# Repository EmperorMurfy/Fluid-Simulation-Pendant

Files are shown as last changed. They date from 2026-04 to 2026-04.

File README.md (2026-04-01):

# Fluid Simulation Pendant
A Fluid Simulation Pendant Inspired by Mitxela

<table>
  <tr>
    <td></td>
    <td></td>
  </tr>
</table>

## Overview
Since January, I've been particularly inspired by Mitxela's Fluid Simulation Pendant.
A watch-sized device, it contains it's own charlieplexed LED display driven by an STM32.
This allows the device to run a particle simulation that responds to gravity in real time.
In other words, water is displayed on it's LED display that flows and settles naturally as you move.
 
As a beginner, I was thoroughly intrigued. This came at the perfect opportunity as I sought to enter electronic design.
So, with no former experience, I set out to build my own from scratch.

You can find my full devlog at [Blueprint](https://blueprint.hackclub.com/projects/14158)
--

## PCB
This project was designed in KiCAD. V1 utilized a lilypad design with two 2-layer daughter boards (see devlog).
V2 features a singular 4-layer board, merging V1's two daughter boards. It tackles significant issues from V1.

### Schematic


### PCB
<table>
  <tr>
    <td></td>
    <td></td>
  </tr>
</table>

## 3D View

<table>
  <tr>
    <td></td>
    <td></td>
  </tr>
</table>

## Setup

OBTAIN PCB
1) Download project files from Github. Use KiCAD to open hardware files.
2) Export & Upload to JLCPCB through Fabrication Toolkit
3) Select PCBA. Make sure you click on Standard + assemble on both sides. 
4) Follow on screen instructions. Verify BOM contents.

5) Purchase and await arrival.

While waiting, you can 3D print the case included in the CAD folder.
Download both "Case.3mf" and "Back Lid.3mf"
Alternatively, you can access the CAD on [Onshape](https://cad.onshape.com/documents/ce3587694f856aec528b28ab/w/4bfd7fa16d33233767ff6bdf/e/73e8d055661068f7b677968e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)

ASSEMBLY 
1) Solder PH1 pins on the back of the PCB at drilled holes labeled BOOT0, NRST, DEBUG_TMS, GND, DEBUG_TCK, 3.3V
2) Connect to Nucleo's ST-LINK, Connect to PCB
3) Install STM32CubeProgrammer and STM32CubeIDE
4) Open software folder from downloaded project files, select STM32.ioc (this should open STM32CubeProgrammer)
5) Select generate code (this should open STM32CubeIDE)
6) Replace the generated main.cp or cpp with main.cp from project files, click run to save
8) Install PCB to case - Be CAREFUL! Putting it at an angle with the USB-C pointed towards the opening helps.
9) Plug the battery into PCB's JST-2 port
10) Install the back lid + push in the watch glass

## BOM
In order to program this device, you will need F to F Jumper Wire and a Nucleo (I used Nucleo-F446RE). 
I didn't include these items as you may already have them. Disclaimer: The cost and quantity of PCB components were determined by JLCPCB.
JLCPCB sources their components from LCSC, but price may be inaccurate. Likewise, JLCPCB charged more components than required (e.g I only need 1040 Green 0402 LEDs, not 1045)
Likewise, you'll need to order 5 PCBs & 2 PCBA minimum. I ordered 5 PCBs + associated PCBA. 

|Item |Qty |Cost  |URL |Reference |Mfg Part # |
|---|----|---|---|---|---|
|PCB |5 |$14.90|https://jlcpcb.com/ |- |- |
|4.7uF-0402 |20  |$0.11 |https://www.lcsc.com/product-detail/C23733.html |C1,C8 |CL05A475MP5NRNC |
|100nF-0402 |40  |$0.05 |https://www.lcsc.com/product-detail/C1525.html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 |C2,C3,C4,C5,C6,C7 |CL05B104KO5NNNC |
|1uF |30  |$0.12 |https://www.lcsc.com/product-detail/C52923.html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 |C9,C10 |CL05A105KA5NQNC |
|1uF-0402 |- |- |https://www.lcsc.com/product-detail/C52923.html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 |C11,C12 |CL05A105KA5NQNC |
|Green 0402 LED |1045|$29.88|https://www.lcsc.com/product-detail/C74338.html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 |D6,D7,D8,D9,D10,D11,D20,D21,D22,D23,D24,D25,D26,D27,D28,D29,D35,D36,D37,D38,D39,D40,D41,D42,D43,D44,D45,D46,D50,D51,D52,D53,D54,D55,D56,D57,D58,D59,D60,D61,D62,D63,D66,D67,D68,D69,D70,D71,D72,D73,D74,D75,D76,D77,D78,D79,D81,D82,D83,D84,D85,D86,D87,D88,D89,D90,D91,D92,D93,D94,D95,D96,D97,D98,D99,D100,D101,D102,D103,D104,D105,D106,D107,D108,D109,D110,D111,D112,D113,D114,D115,D116,D117,D118,D119,D120,D121,D122,D123,D124,D125,D126,D127,D128,D129,D130,D131,D132,D133,D134,D135,D136,D137,D138,D139,D140,D141,D142,D143,D144,D145,D146,D147,D148,D149,D150,D151,D152,D153,D154,D155,D156,D157,D158,D159,D160,D161,D162,D163,D164,D165,D166,D167,D168,D169,D170,D171,D172,D173,D174,D175,D176,D178,D179,D180,D181,D182,D183,D184,D185,D186,D187,D188,D189,D190,D191,D194,D195,D196,D197,D198,D199,D200,D201,D202,D203,D204,D205,D206,D207,D211,D212,D213,D214,D215,D216,D217,D218,D219,D220,D221,D222,D228,D229,D230,D231,D232,D233,D234,D235,D236,D237,D246,D247,D248,D249,D250,D251|16-213/GHC-YR1S1/3T |
|Red 0402 LED |5 |$0.35 |https://www.lcsc.com/product-detail/C264407.html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|D257 |16-213/R6C-AQ2R2B/3T  |
|Conn_01x01_Pin |125 |- |- |J2,J3,J4,J5,J6,J7,J8,J9,J10,J11,J12,J13,J14,J15,J16,J17,J18,J19,J20,J21,J22,J23,J24,J25,J26 |DNP |
|Conn_01x02_Socket |5 |$2.19 |https://www.lcsc.com/product-detail/C160352.html?s_z=n_C160352 |J44 |B2B-PH-SM4-TB(LF)(SN) |
|22 |95  |$0.08 |https://www.lcsc.com/product-detail/C25092.html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 |R1,R2,R3,R4,R5,R6,R7,R8,R9,R10,R11,R12,R13,R14,R15,R16,R17 |0402WGF220JTCE |
|20K |20  |$0.02 |https://www.lcsc.com/product-detail/C25765.html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 |R18 |0402WGF2002TCE |
|1k |20  |$0.01 |https://www.lcsc.com/product-detail/C11702.html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 |R19 |0402WGF1001TC |
|10k |25  |$0.03 |https://www.lcsc.com/product-detail/C25744.html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 |R20, R21,R22 |0402WGF1002TCE |
|5.1K |20  |$0.02 |https://www.lcsc.com/product-detail/C25905.html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 |R23,R24 |0402WGF5101TCE |
|TestPoint |15  | |- |TP1,TP2,TP3 |DNP |
|STM32U575RGTx |5 |$27.84| |U1 |STM32U575RGT6 |
|ADXL363 |5 |$90.77|https://www.lcsc.com/product-detail/C579464.html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 |U2 |ADXL363BCCZ-RL7 |
|USBLC6-2P6 |5 |$1.23 |https://www.lcsc.com/product-detail/C15999.html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 |U3 |USBLC6-2P6 |
|MCP73832-2-MC |5 |$5.19 |https://www.lcsc.com/product-detail/C511264.html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 |U4 |MCP73832T-2ACI/MC |
|TPS7A20xxxDQN |5 |$1.59 |https://www.lcsc.com/product-detail/C46459900.html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 |U5 |TPS7A2033DQNR |
|TYPE-C_16P_QTWT |5 |$0.45 |https://www.lcsc.com/product-detail/C5187472.html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|USB1 |TYPE-C 16P QTWT |
|Setup Fee |- |$50.74|- |- |- |
|Stencil |- |$16.30|- |- |- |
|Feeders Loading Fee |- |$25.84|- |- |- |
|SMT Assembly |- |$5.23 |- |- |- |
|Packaging Fee | |$0.49 |- |- |- |
|JLCPCB Shipping |- |$50.04|- |- |- |
|JLCPCB Custom Duties & Taxes |- |$86.68|- |- |- |
|Li-Polymer 402025 150mAh 3.7V|5 |$29.75|https://www.digikey.com/en/products/detail/adafruit-industries-llc/1317/5054547 |- |- |
|PH1-01-UA |40  |$1.16 |https://www.digikey.com/en/products/detail/adam-tech/PH1-01-UA/9830231 |- |- |
|Digikey Shipping |- |$6.99 |- |- |- |
|Watch Glass 43mm Dia |1 |$7.69 |https://www.amazon.com/dp/B09QXCGNG6?ref_=ppx_hzsearch_conn_dt_b_fed_asin_title_1 | | |
|Total |- |$456  | | | |

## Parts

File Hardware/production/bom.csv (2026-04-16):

Designator | Footprint | Quantity | Value | LCSC Part #
C1, C8 | 0402 | 2 | 4.7uF-0402
C10, C9 | 0402 | 2 | 1uF
C11, C12 | 0402 | 2 | 1uF-0402
C2, C3, C4, C5, C6, C7 | 0402 | 6 | 100nF-0402
D10, D100, D101, D102, D103, D104, D105, D106, D107, D108, D109, D11, D110, D111, D112, D113, D114, D115, D116, D117, D118, D119, D120, D121, D122, D123, D124, D125, D126, D127, D128, D129, D130, D131, D132, D133, D134, D135, D136, D137, D138, D139, D140, D141, D142, D143, D144, D145, D146, D147, D148, D149, D150, D151, D152, D153, D154, D155, D156, D157, D158, D159, D160, D161, D162, D163, D164, D165, D166, D167, D168, D169, D170, D171, D172, D173, D174, D175, D176, D178, D179, D180, D181, D182, D183, D184, D185, D186, D187, D188, D189, D190, D191, D194, D195, D196, D197, D198, D199, D20, D200, D201, D202, D203, D204, D205, D206, D207, D21, D211, D212, D213, D214, D215, D216, D217, D218, D219, D22, D220, D221, D222, D228, D229, D23, D230, D231, D232, D233, D234, D235, D236, D237, D24, D246, D247, D248, D249, D25, D250, D251, D26, D27, D28, D29, D35, D36, D37, D38, D39, D40, D41, D42, D43, D44, D45, D46, D50, D51, D52, D53, D54, D55, D56, D57, D58, D59, D6, D60, D61, D62, D63, D66, D67, D68, D69, D7, D70, D71, D72, D73, D74, D75, D76, D77, D78, D79, D8, D81, D82, D83, D84, D85, D86, D87, D88, D89, D9, D90, D91 | 0402 | 200 | Green 0402 LED
D257 | 0402 | 1 | Red 0402 LED
D92, D93, D94, D95, D96, D97, D98, D99 | 0402 | 8 | Green 0402 LED
J10, J11, J12, J13, J14, J15, J16, J17, J18, J19, J2, J20, J21, J22, J23, J24, J25, J26, J3, J4, J5, J6, J7, J8, J9 | TestPoint_THTPad_D2.0mm_Drill1.0mm | 25 | Conn_01x01_Pin
J44 | JST_PH_B2B-PH-SM4-TB_1x02-1MP_P2.00mm_Vertical | 1 | Conn_01x02_Socket
R1, R10, R11, R12, R13, R14, R15, R16, R17, R2, R3, R4, R5, R6, R7, R8, R9 | 0402 | 17 | 22
R18 | 0402 | 1 | 20K
R19 | 0402 | 1 | 1k
R20, R21, R22 | 0402 | 3 | 10k
R23, R24 | 0402 | 2 | 5.1K
TP1, TP2, TP3 | TestPoint_Pad_2.0x2.0mm | 3 | TestPoint
U1 | LQFP-64_10x10mm_P0.5mm | 1 | STM32U575RGTx
U2 | Analog_LGA-16_3.25x3mm_P0.5mm_LayoutBorder3x5y | 1 | ADXL363
U3 | SOT-666 | 1 | USBLC6-2P6
U4 | DFN-8-1EP_3x2mm_P0.5mm_EP1.7x1.4mm | 1 | MCP73832-2-MC
U5 | Texas_X2SON-4_1x1mm_P0.65mm | 1 | TPS7A20xxxDQN
USB1 | TYPE-C_16P_QTWT | 1 | TYPE-C_16P_QTWT | C5187472

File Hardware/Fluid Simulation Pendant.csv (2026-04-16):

Reference | Mfg Part # | LCSC | Link | Qty | Value | DNP | Exclude from BOM | Exclude from Board | Footprint | Datasheet | Manufacturer
C1,C8 | CL05A475MP5NRNC |  |  | 2 | 4.7uF-0402 |  |  |  | Capacitor_SMD:C_0402_1005Metric | ~ | Murata Electronics
C2,C3,C4,C5,C6,C7 | CL05B104KO5NNNC |  |  | 6 | 100nF-0402 |  |  |  | Capacitor_SMD:C_0402_1005Metric | ~ | Murata Electronics
C9,C10 | CL05A105KA5NQNC |  |  | 2 | 1uF |  |  |  | Capacitor_SMD:C_0402_1005Metric | ~ | Murata Electronics
C11,C12 | CL05A105KA5NQNC |  |  | 2 | 1uF-0402 |  |  |  | Capacitor_SMD:C_0402_1005Metric | ~ | Murata Electronics
D6,D7,D8,D9,D10,D11,D20,D21,D22,D23,D24,D25,D26,D27,D28,D29,D35,D36,D37,D38,D39,D40,D41,D42,D43,D44,D45,D46,D50,D51,D52,D53,D54,D55,D56,D57,D58,D59,D60,D61,D62,D63,D66,D67,D68,D69,D70,D71,D72,D73,D74,D75,D76,D77,D78,D79,D81,D82,D83,D84,D85,D86,D87,D88,D89,D90,D91,D92,D93,D94,D95,D96,D97,D98,D99,D100,D101,D102,D103,D104,D105,D106,D107,D108,D109,D110,D111,D112,D113,D114,D115,D116,D117,D118,D119,D120,D121,D122,D123,D124,D125,D126,D127,D128,D129,D130,D131,D132,D133,D134,D135,D136,D137,D138,D139,D140,D141,D142,D143,D144,D145,D146,D147,D148,D149,D150,D151,D152,D153,D154,D155,D156,D157,D158,D159,D160,D161,D162,D163,D164,D165,D166,D167,D168,D169,D170,D171,D172,D173,D174,D175,D176,D178,D179,D180,D181,D182,D183,D184,D185,D186,D187,D188,D189,D190,D191,D194,D195,D196,D197,D198,D199,D200,D201,D202,D203,D204,D205,D206,D207,D211,D212,D213,D214,D215,D216,D217,D218,D219,D220,D221,D222,D228,D229,D230,D231,D232,D233,D234,D235,D236,D237,D246,D247,D248,D249,D250,D251 | 16-213/GHC-YR1S1/3T |  |  | 208 | Green 0402 LED |  |  |  | LED_SMD:LED_0402_1005Metric | ~ | Everlight Electronics Co Ltd
D257 | 16-213/R6C-AQ2R2B/3T |  |  | 1 | Red 0402 LED |  |  |  | LED_SMD:LED_0402_1005Metric | ~ | Everlight Electronics Co Ltd
J2,J3,J4,J5,J6,J7,J8,J9,J10,J11,J12,J13,J14,J15,J16,J17,J18,J19,J20,J21,J22,J23,J24,J25,J26 |  |  |  | 25 | Conn_01x01_Pin | DNP |  |  | TestPoint:TestPoint_THTPad_D2.0mm_Drill1.0mm | ~
J44 | B2B-PH-SM4-TB(LF)(SN) |  |  | 1 | Conn_01x02_Socket |  |  |  | Connector_JST:JST_PH_B2B-PH-SM4-TB_1x02-1MP_P2.00mm_Vertical | ~
R1,R2,R3,R4,R5,R6,R7,R8,R9,R10,R11,R12,R13,R14,R15,R16,R17 | 0402WGF220JTCE |  |  | 17 | 22 |  |  |  | Resistor_SMD:R_0402_1005Metric | ~ | YAGEO
R18 | 0402WGF2002TCE |  |  | 1 | 20K |  |  |  | Resistor_SMD:R_0402_1005Metric | ~
R19 | 0402WGF1001TC |  |  | 1 | 1k |  |  |  | Resistor_SMD:R_0402_1005Metric | ~ | YAGEO
R20 | 0402WGF1002TCE |  |  | 1 | 10k |  |  |  | Resistor_SMD:R_0402_1005Metric | ~ | YAGEO
R21,R22 | 0402WGF1002TCE |  |  | 2 | 10K |  |  |  | Resistor_SMD:R_0402_1005Metric | ~
R23,R24 | 0402WGF5101TCE |  |  | 2 | 5.1K |  |  |  | Resistor_SMD:R_0402_1005Metric | ~
TP1,TP2,TP3 |  |  |  | 3 | TestPoint | DNP |  |  | TestPoint:TestPoint_Pad_2.0x2.0mm | ~
U1 | STM32U575RGT6 |  |  | 1 | STM32U575RGTx |  |  |  | Package_QFP:LQFP-64_10x10mm_P0.5mm | https://www.st.com/resource/en/datasheet/stm32u575rg.pdf | STMicroelectronics
U2 | ADXL363BCCZ-RL7 |  |  | 1 | ADXL363 |  |  |  | Sensor_Motion:Analog_LGA-16_3.25x3mm_P0.5mm_LayoutBorder3x5y | https://www.analog.com/media/en/technical-documentation/data-sheets/ADXL363.pdf | Analog Devices Inc.
U3 | USBLC6-2P6 |  |  | 1 | USBLC6-2P6 |  |  |  | Package_TO_SOT_SMD:SOT-666 | https://www.st.com/resource/en/datasheet/usblc6-2.pdf | STMicroelectronics
U4 | MCP73832T-2ACI/MC |  |  | 1 | MCP73832-2-MC |  |  |  | Package_DFN_QFN:DFN-8-1EP_3x2mm_P0.5mm_EP1.7x1.4mm | http://ww1.microchip.com/downloads/en/DeviceDoc/20001984g.pdf | Microchip Tech
U5 | TPS7A2033DQNR |  |  | 1 | TPS7A20xxxDQN |  |  |  | Package_SON:Texas_X2SON-4_1x1mm_P0.65mm | https://www.ti.com/lit/ds/symlink/tps7a20.pdf | Texas Instruments
USB1 | TYPE-C 16P QTWT | C5187472 |  | 1 | TYPE-C_16P_QTWT |  |  |  | JLCImport:TYPE-C_16P_QTWT | https://wmsc.lcsc.com/wmsc/upload/file/pdf/v2/lcsc/2209291730_SHOU-HAN-TYPE-C-16P-QTWT_C5187472.pdf | SHOU HAN

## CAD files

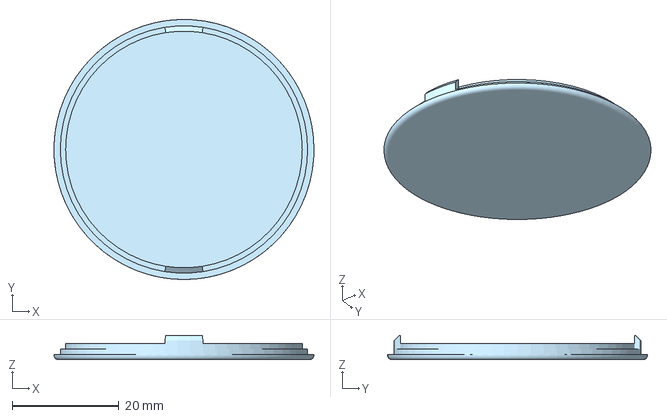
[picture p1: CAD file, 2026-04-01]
CAD/Back Lid.3mf
48.8 x 48.8 x 4.58 mm

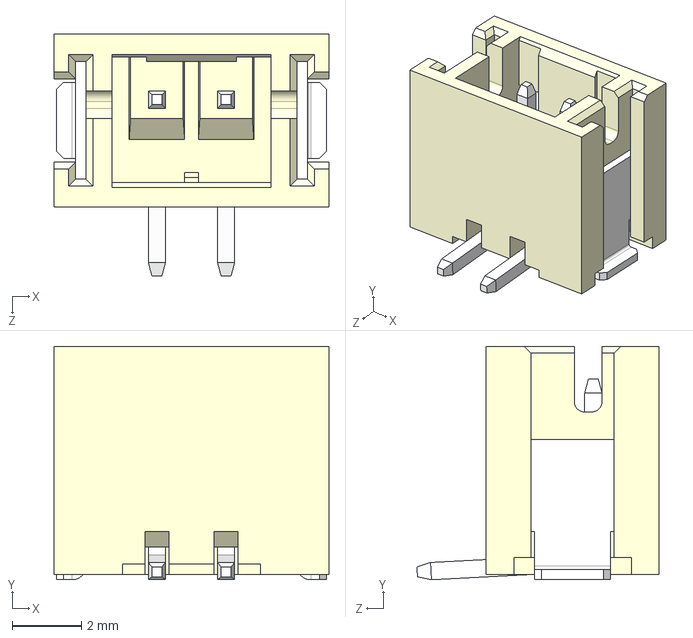
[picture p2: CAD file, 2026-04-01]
Hardware/B2B-PH-SM4-TB(LF)(SN).STEP
7.95 x 6.75 x 7.00 mm

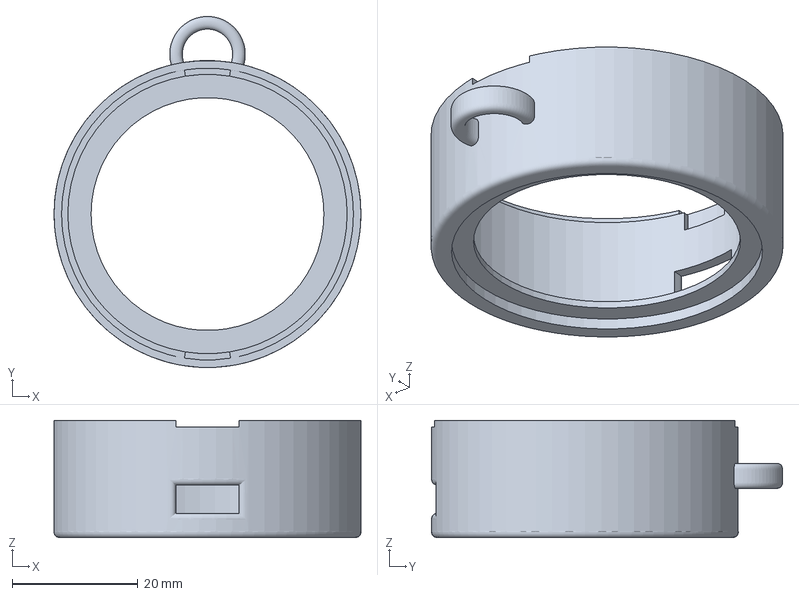
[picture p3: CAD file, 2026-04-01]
CAD/Case.3mf
48.8 x 55.8 x 18.6 mm

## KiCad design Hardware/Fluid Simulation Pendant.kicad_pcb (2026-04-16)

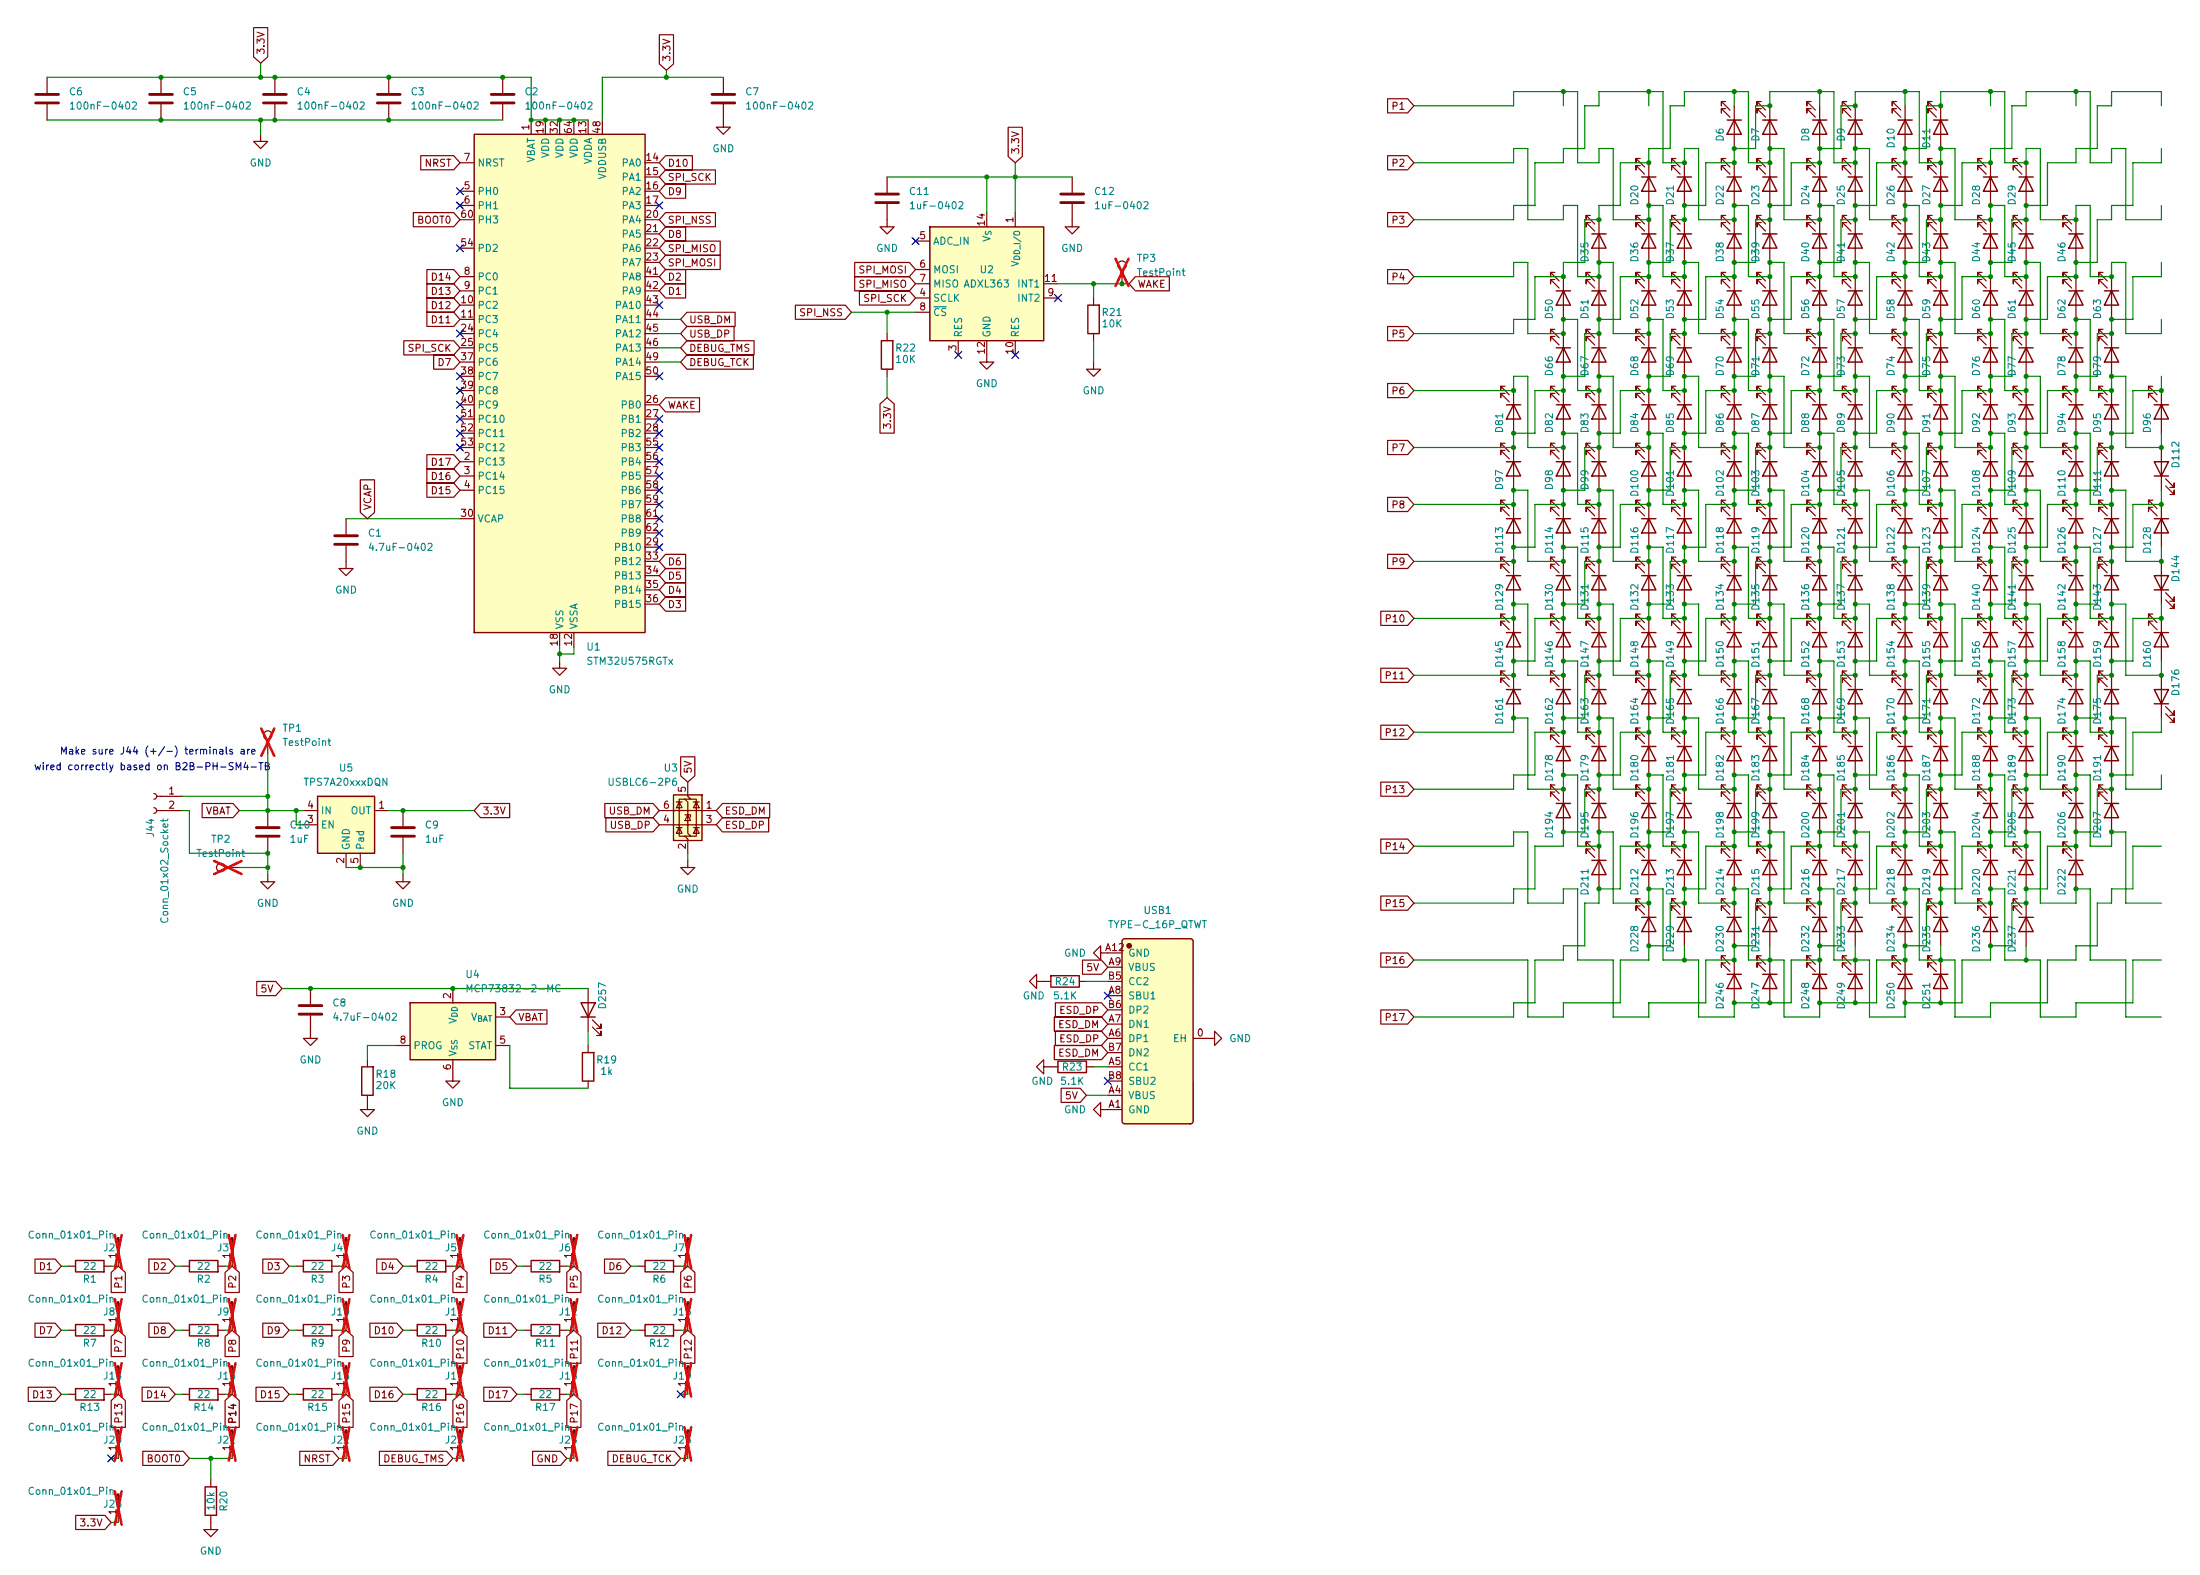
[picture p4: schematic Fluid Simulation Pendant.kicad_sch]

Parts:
C1, C8: 4.7uF-0402; C_0402_1005Metric; Mfg Part # CL05A475MP5NRNC
C2, C3, C4, C5, C6, C7: 100nF-0402; C_0402_1005Metric; Mfg Part # CL05B104KO5NNNC
C9, C10: 1uF; C_0402_1005Metric; Mfg Part # CL05A105KA5NQNC
C11, C12: 1uF-0402; C_0402_1005Metric; Mfg Part # CL05A105KA5NQNC
D6, D7, D8, D9, D10, D11, D20, D21, D22, D23, D24, D25, D26, D27, D28, D29, D35, D36, D37, D38, D39, D40, D41, D42, D43, D44, D45, D46, D50, D51, D52, D53, D54, D55, D56, D57, D58, D59, D60, D61, D62, D63, D66, D67, D68, D69, D70, D71, D72, D73, D74, D75, D76, D77, D78, D79, D81, D82, D83, D84, D85, D86, D87, D88, D89, D90, D91, D92, D93, D94, D95, D96, D97, D98, D99, D100, D101, D102, D103, D104, D105, D106, D107, D108, D109, D110, D111, D112, D113, D114, D115, D116, D117, D118, D119, D120, D121, D122, D123, D124, D125, D126, D127, D128, D129, D130, D131, D132, D133, D134, D135, D136, D137, D138, D139, D140, D141, D142, D143, D144, D145, D146, D147, D148, D149, D150, D151, D152, D153, D154, D155, D156, D157, D158, D159, D160, D161, D162, D163, D164, D165, D166, D167, D168, D169, D170, D171, D172, D173, D174, D175, D176, D178, D179, D180, D181, D182, D183, D184, D185, D186, D187, D188, D189, D190, D191, D194, D195, D196, D197, D198, D199, D200, D201, D202, D203, D204, D205, D206, D207, D211, D212, D213, D214, D215, D216, D217, D218, D219, D220, D221, D222, D228, D229, D230, D231, D232, D233, D234, D235, D236, D237, D246, D247, D248, D249, D250, D251: Green 0402 LED; LED_0402_1005Metric; Mfg Part # 16-213/GHC-YR1S1/3T
D257: Red 0402 LED; LED_0402_1005Metric; Mfg Part # 16-213/R6C-AQ2R2B/3T
J2, J3, J4, J5, J6, J7, J8, J9, J10, J11, J12, J13, J14, J15, J16, J17, J18, J19, J20, J21, J22, J23, J24, J25, J26: Conn_01x01_Pin; TestPoint_THTPad_D2.0mm_Drill1.0mm; not fitted
J44: Conn_01x02_Socket; JST_PH_B2B-PH-SM4-TB_1x02-1MP_P2.00mm_Vertical; Mfg Part # B2B-PH-SM4-TB(LF)(SN)
R1, R2, R3, R4, R5, R6, R7, R8, R9, R10, R11, R12, R13, R14, R15, R16, R17: 22; R_0402_1005Metric; Mfg Part # 0402WGF220JTCE
R18: 20K; R_0402_1005Metric; Mfg Part # 0402WGF2002TCE
R19: 1k; R_0402_1005Metric; Mfg Part # 0402WGF1001TC
R20: 10k; R_0402_1005Metric; Mfg Part # 0402WGF1002TCE
R21, R22: 10K; R_0402_1005Metric; Mfg Part # 0402WGF1002TCE
R23, R24: 5.1K; R_0402_1005Metric; Mfg Part # 0402WGF5101TCE
TP1, TP2, TP3: TestPoint; TestPoint_Pad_2.0x2.0mm; not fitted
U1: STM32U575RGTx; LQFP-64_10x10mm_P0.5mm; Mfg Part # STM32U575RGT6
U2: ADXL363; Analog_LGA-16_3.25x3mm_P0.5mm_LayoutBorder3x5y; Mfg Part # ADXL363BCCZ-RL7
U3: USBLC6-2P6; SOT-666; Mfg Part # USBLC6-2P6
U4: MCP73832-2-MC; DFN-8-1EP_3x2mm_P0.5mm_EP1.7x1.4mm; Mfg Part # MCP73832T-2ACI/MC
U5: TPS7A20xxxDQN; Texas_X2SON-4_1x1mm_P0.65mm; Mfg Part # TPS7A2033DQNR
USB1: TYPE-C_16P_QTWT; Manufacturer Part TYPE-C 16P QTWT; LCSC C5187472

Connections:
3.3V: C2.1, C3.1, C4.1, C5.1, C6.1, C7.1, C9.1, C11.1, C12.1, J26.1, R22.1, U1.1 (VBAT), U1.13 (VDDA), U1.19 (VDD), U1.32 (VDD), U1.48 (VDDUSB), U1.64 (VDD), U2.1 (V_{DD_I/O}), U2.14 (V_{S}), U5.1 (OUT)
5V: C8.1, D257.2 (A), U3.5 (VBUS), U4.1 (V_{DD}), U4.2 (V_{DD}), USB1.A4 (VBUS), USB1.A9 (VBUS)
BOOT0: J21.1, R20.2, U1.60 (PH3)
D1: R1.1, U1.42 (PA9)
D2: R2.1, U1.41 (PA8)
D3: R3.1, U1.36 (PB15)
D4: R4.1, U1.35 (PB14)
D5: R5.1, U1.34 (PB13)
D6: R6.1, U1.33 (PB12)
D7: R7.1, U1.37 (PC6)
D8: R8.1, U1.21 (PA5)
D9: R9.1, U1.16 (PA2)
D10: R10.1, U1.14 (PA0)
D11: R11.1, U1.11 (PC3)
D12: R12.1, U1.10 (PC2)
D13: R13.1, U1.9 (PC1)
D14: R14.1, U1.8 (PC0)
D15: R15.1, U1.4 (PC15)
D16: R16.1, U1.3 (PC14)
D17: R17.1, U1.2 (PC13)
DEBUG_TCK: J25.1, U1.49 (PA14)
DEBUG_TMS: J23.1, U1.46 (PA13)
ESD_DM: U3.1 (I/O1), USB1.A7 (DN1), USB1.B7 (DN2)
ESD_DP: U3.3 (I/O2), USB1.A6 (DP1), USB1.B6 (DP2)
GND: C1.2, C2.2, C3.2, C4.2, C5.2, C6.2, C7.2, C8.2, C9.2, C10.2, C11.2, C12.2, J24.1, J44.2, R18.1, R20.1, R21.1, R23.1, R24.2, TP2.1, U1.12 (VSSA), U1.18 (VSS), U1.31 (VSS), U1.47 (VSS), U1.63 (VSS), U2.12 (GND), U2.13 (GND), U2.16 (GND), U3.2 (GND), U4.6 (V_{SS}), U5.2 (GND), U5.5 (Pad), USB1.0 (EH), USB1.A1 (GND), USB1.A12 (GND)
NRST: J22.1, U1.7 (NRST)
unnamed: D257.1 (K), R19.2
unnamed: R18.2, U4.8 (PROG)
unnamed: R19.1, U4.5 (STAT)
unnamed: R23.2, USB1.A5 (CC1)
unnamed: R24.1, USB1.B5 (CC2)
P1: D20.2 (A), D36.1 (K), D37.2 (A), D53.1 (K), D54.2 (A), D70.1 (K), D71.2 (A), D87.1 (K), D88.2 (A), D104.1 (K), D105.2 (A), D121.1 (K), D122.2 (A), D138.1 (K), D139.2 (A), D155.1 (K), D156.2 (A), D172.1 (K), D173.2 (A), D189.1 (K), D190.2 (A), D206.1 (K), D207.2 (A), J2.1, R1.2
P2: D35.2 (A), D51.1 (K), D52.2 (A), D68.1 (K), D69.2 (A), D85.1 (K), D86.2 (A), D102.1 (K), D103.2 (A), D119.1 (K), D120.2 (A), D136.1 (K), D137.2 (A), D153.1 (K), D154.2 (A), D170.1 (K), D171.2 (A), D187.1 (K), D188.2 (A), D204.1 (K), D205.2 (A), D221.1 (K), D222.2 (A), J3.1, R2.2
P3: D21.1 (K), D22.2 (A), D38.1 (K), D39.2 (A), D55.1 (K), D56.2 (A), D72.1 (K), D73.2 (A), D89.1 (K), D90.2 (A), D106.1 (K), D107.2 (A), D123.1 (K), D124.2 (A), D140.1 (K), D141.2 (A), D157.1 (K), D158.2 (A), D174.1 (K), D175.2 (A), D191.1 (K), J4.1, R3.2
P4: D50.2 (A), D66.1 (K), D67.2 (A), D83.1 (K), D84.2 (A), D100.1 (K), D101.2 (A), D117.1 (K), D118.2 (A), D134.1 (K), D135.2 (A), D151.1 (K), D152.2 (A), D168.1 (K), D169.2 (A), D185.1 (K), D186.2 (A), D202.1 (K), D203.2 (A), D219.1 (K), D220.2 (A), D236.1 (K), D237.2 (A), J5.1, R4.2
P5: D6.1 (K), D7.2 (A), D20.1 (K), D23.1 (K), D24.2 (A), D35.1 (K), D40.1 (K), D41.2 (A), D50.1 (K), D57.1 (K), D58.2 (A), D74.1 (K), D75.2 (A), D91.1 (K), D92.2 (A), D108.1 (K), D109.2 (A), D125.1 (K), D126.2 (A), D142.1 (K), D143.2 (A), D159.1 (K), D160.2 (A), D176.2 (A), J6.1, R5.2
P6: D81.1 (K), D82.2 (A), D98.1 (K), D99.2 (A), D115.1 (K), D116.2 (A), D132.1 (K), D133.2 (A), D149.1 (K), D150.2 (A), D166.1 (K), D167.2 (A), D183.1 (K), D184.2 (A), D200.1 (K), D201.2 (A), D217.1 (K), D218.2 (A), D234.1 (K), D235.2 (A), D251.1 (K), J7.1, R6.2
P7: D6.2 (A), D7.1 (K), D8.1 (K), D9.2 (A), D21.2 (A), D22.1 (K), D25.1 (K), D26.2 (A), D36.2 (A), D37.1 (K), D42.1 (K), D43.2 (A), D51.2 (A), D52.1 (K), D59.1 (K), D60.2 (A), D66.2 (A), D67.1 (K), D76.1 (K), D77.2 (A), D81.2 (A), D82.1 (K), D93.1 (K), D94.2 (A), D97.1 (K), D110.1 (K), D111.2 (A), D127.1 (K), D128.2 (A), D144.2 (A), J8.1, R7.2
P8: D97.2 (A), D113.1 (K), D114.2 (A), D130.1 (K), D131.2 (A), D147.1 (K), D148.2 (A), D164.1 (K), D165.2 (A), D176.1 (K), D181.1 (K), D182.2 (A), D191.2 (A), D198.1 (K), D199.2 (A), D206.2 (A), D207.1 (K), D215.1 (K), D216.2 (A), D221.2 (A), D222.1 (K), D232.1 (K), D233.2 (A), D236.2 (A), D237.1 (K), D249.1 (K), D250.2 (A), D251.2 (A), J9.1, R8.2
P9: D8.2 (A), D9.1 (K), D10.1 (K), D11.2 (A), D23.2 (A), D24.1 (K), D27.1 (K), D28.2 (A), D38.2 (A), D39.1 (K), D44.1 (K), D45.2 (A), D53.2 (A), D54.1 (K), D61.1 (K), D62.2 (A), D68.2 (A), D69.1 (K), D78.1 (K), D79.2 (A), D83.2 (A), D84.1 (K), D95.1 (K), D96.2 (A), D98.2 (A), D99.1 (K), D112.2 (A), D113.2 (A), D114.1 (K), D129.1 (K), J10.1, R9.2
P10: D129.2 (A), D144.1 (K), D145.1 (K), D146.2 (A), D159.2 (A), D160.1 (K), D162.1 (K), D163.2 (A), D174.2 (A), D175.1 (K), D179.1 (K), D180.2 (A), D189.2 (A), D190.1 (K), D196.1 (K), D197.2 (A), D204.2 (A), D205.1 (K), D213.1 (K), D214.2 (A), D219.2 (A), D220.1 (K), D230.1 (K), D231.2 (A), D234.2 (A), D235.1 (K), D247.1 (K), D248.2 (A), D249.2 (A), D250.1 (K), J11.1, R10.2
P11: D10.2 (A), D11.1 (K), D25.2 (A), D26.1 (K), D29.1 (K), D40.2 (A), D41.1 (K), D46.1 (K), D55.2 (A), D56.1 (K), D63.1 (K), D70.2 (A), D71.1 (K), D85.2 (A), D86.1 (K), D100.2 (A), D101.1 (K), D115.2 (A), D116.1 (K), D130.2 (A), D131.1 (K), D145.2 (A), D146.1 (K), D161.1 (K), J12.1, R11.2
P12: D112.1 (K), D127.2 (A), D128.1 (K), D142.2 (A), D143.1 (K), D157.2 (A), D158.1 (K), D161.2 (A), D172.2 (A), D173.1 (K), D178.2 (A), D187.2 (A), D188.1 (K), D194.1 (K), D195.2 (A), D202.2 (A), D203.1 (K), D211.1 (K), D212.2 (A), D217.2 (A), D218.1 (K), D228.1 (K), D229.2 (A), D232.2 (A), D233.1 (K), D246.2 (A), D247.2 (A), D248.1 (K), J13.1, R12.2
P13: D27.2 (A), D28.1 (K), D42.2 (A), D43.1 (K), D57.2 (A), D58.1 (K), D72.2 (A), D73.1 (K), D87.2 (A), D88.1 (K), D102.2 (A), D103.1 (K), D117.2 (A), D118.1 (K), D132.2 (A), D133.1 (K), D147.2 (A), D148.1 (K), D162.2 (A), D163.1 (K), D178.1 (K), J14.1, R13.2
P14: D95.2 (A), D96.1 (K), D110.2 (A), D111.1 (K), D125.2 (A), D126.1 (K), D140.2 (A), D141.1 (K), D155.2 (A), D156.1 (K), D170.2 (A), D171.1 (K), D185.2 (A), D186.1 (K), D200.2 (A), D201.1 (K), D215.2 (A), D216.1 (K), D230.2 (A), D231.1 (K), D246.1 (K), J15.1, R14.2
P15: D29.2 (A), D44.2 (A), D45.1 (K), D59.2 (A), D60.1 (K), D74.2 (A), D75.1 (K), D89.2 (A), D90.1 (K), D104.2 (A), D105.1 (K), D119.2 (A), D120.1 (K), D134.2 (A), D135.1 (K), D149.2 (A), D150.1 (K), D164.2 (A), D165.1 (K), D179.2 (A), D180.1 (K), D194.2 (A), D195.1 (K), J16.1, R15.2
P16: D63.2 (A), D78.2 (A), D79.1 (K), D93.2 (A), D94.1 (K), D108.2 (A), D109.1 (K), D123.2 (A), D124.1 (K), D138.2 (A), D139.1 (K), D153.2 (A), D154.1 (K), D168.2 (A), D169.1 (K), D183.2 (A), D184.1 (K), D198.2 (A), D199.1 (K), D213.2 (A), D214.1 (K), D228.2 (A), D229.1 (K), J17.1, R16.2
P17: D46.2 (A), D61.2 (A), D62.1 (K), D76.2 (A), D77.1 (K), D91.2 (A), D92.1 (K), D106.2 (A), D107.1 (K), D121.2 (A), D122.1 (K), D136.2 (A), D137.1 (K), D151.2 (A), D152.1 (K), D166.2 (A), D167.1 (K), D181.2 (A), D182.1 (K), D196.2 (A), D197.1 (K), D211.2 (A), D212.1 (K), J18.1, R17.2
SPI_MISO: U1.22 (PA6), U2.7 (MISO)
SPI_MOSI: U1.23 (PA7), U2.6 (MOSI)
SPI_NSS: R22.2, U1.20 (PA4), U2.8 (~CS)
SPI_SCK: U1.15 (PA1), U1.25 (PC5), U2.4 (SCLK)
USB_DM: U1.44 (PA11), U3.6 (I/O1)
USB_DP: U1.45 (PA12), U3.4 (I/O2)
VBAT: C10.1, J44.1, TP1.1, U4.3 (V_{BAT}), U4.4 (V_{BAT}), U5.3 (EN), U5.4 (IN)
VCAP: C1.1, U1.30 (VCAP)
WAKE: R21.2, TP3.1, U1.26 (PB0), U2.11 (INT1)

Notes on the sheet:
Make sure J44 (+/-) terminals are
wired correctly based on B2B-PH-SM4-TB

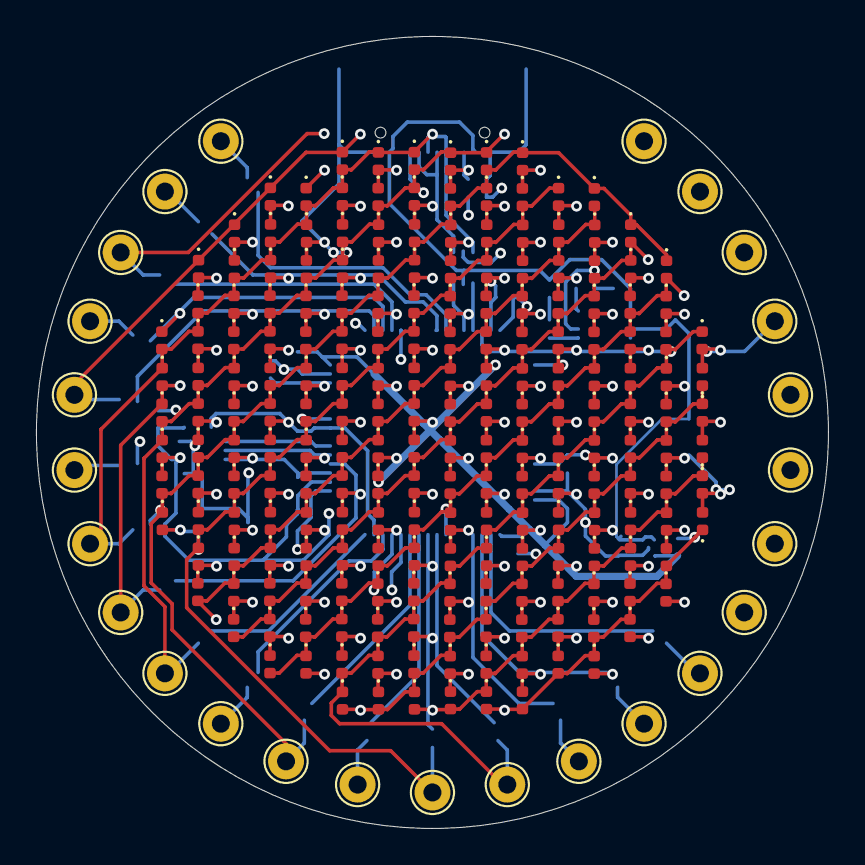
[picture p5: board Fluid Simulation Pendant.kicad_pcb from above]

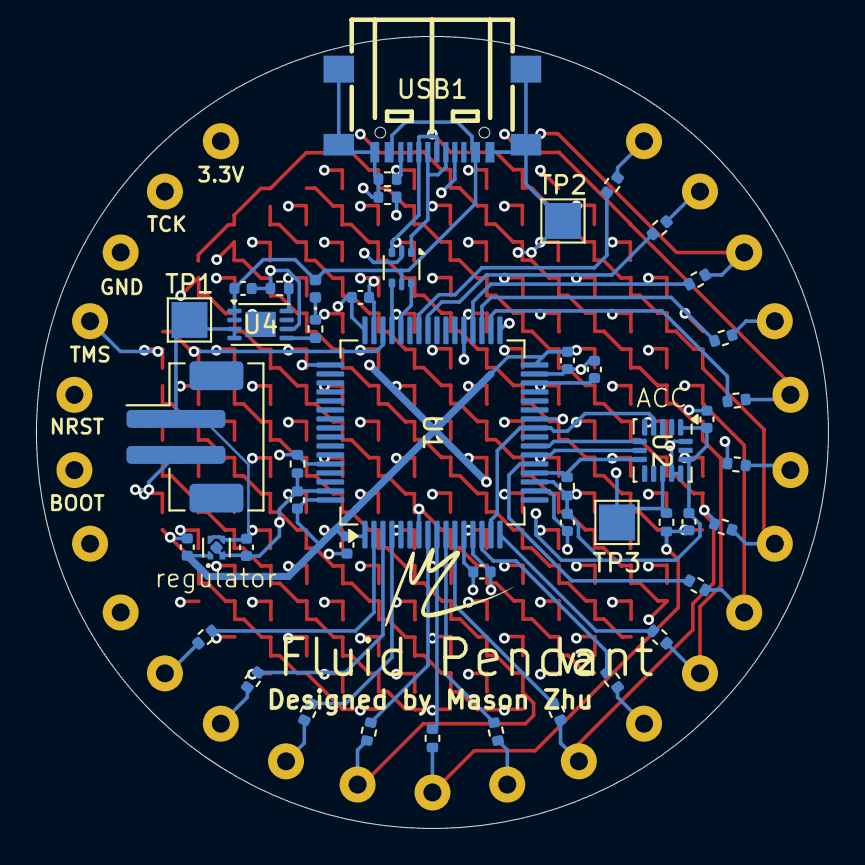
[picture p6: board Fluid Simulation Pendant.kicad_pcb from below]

Board: 4 copper layers, 44.0 x 44.0 mm, 280 parts (47 on the bottom side), 57 nets.

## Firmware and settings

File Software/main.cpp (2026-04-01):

/*
MIT License

Copyright (c) 2026 Mason Z.

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
THE SOFTWARE IS PROVIDED "AS IS", WITHOUT WARRANTY OF ANY KIND, EXPRESS OR
IMPLIED, INCLUDING BUT NOT LIMITED TO THE WARRANTIES OF MERCHANTABILITY,
FITNESS FOR A PARTICULAR PURPOSE AND NONINFRINGEMENT. IN NO EVENT SHALL THE
AUTHORS OR COPYRIGHT HOLDERS BE LIABLE FOR ANY CLAIM, DAMAGES OR OTHER
LIABILITY, WHETHER IN AN ACTION OF CONTRACT, TORT OR OTHERWISE, ARISING FROM,
OUT OF OR IN CONNECTION WITH THE SOFTWARE OR THE USE OR OTHER DEALINGS IN THE
SOFTWARE.
-->
*/

#include "main.h"
#include "spi.h"
#include "gpio.h"
#include "icache.h"
#include "tim.h"
#include <cstring>
#include <cmath>
#include <cstdint>

extern "C" {
    void SystemClock_Config(void);
    void Error_Handler(void);
}

extern SPI_HandleTypeDef hspi1;
extern TIM_HandleTypeDef htim2;

// Simulation Parameters 
#define NUM_PARTICLES           50      // particle count - adjustable
#define GRAVITY_STRENGTH        40.0f   // gravity - adjustable
#define SIM_RADIUS              8.0f    // simulation radius - do not touch
#define DT                      0.025f  // delta time - do not touch
#define PARTICLE_REPULSE        1.3f    // min distance between each particle - do not touch
#define DAMPING                 0.78f   // velocity scale on wall bounce - adjustable
#define RESTITUTION             1.35f   // Bounce reflection multiplier - adjustable
#define MUX_DWELL_US            30      // LED refresh rate - do not touch
#define PHYSICS_STEPS_PER_PASS  1       // physics steps per frame - do not touch
#define ACCEL_READ_INTERVAL     8       // sensor read every N physics steps - do not touch

// Activity / Sleep
#define ACTIVITY_THRESHOLD      50.0f    // gravity unit change to count as movement
#define SLEEP_AFTER_SECONDS     50      // seconds of inactivity before sleep

#define READS_PER_SECOND        (1000 / (ACCEL_READ_INTERVAL * 16))
#define INACTIVITY_COUNT_MAX    (SLEEP_AFTER_SECONDS * READS_PER_SECOND)

static bool is_sleeping = false;

// LED Mapping
const int8_t anode_map[256] = {
    -1, -1, -1, -1, -1,  7,  5,  9,  7, 11,  9, -1, -1, -1, -1, -1,
    -1, -1, -1,  1,  7,  3,  9,  5, 11,  7, 13,  9, 15, -1, -1, -1,
    -1, -1,  2,  7,  1,  9,  3, 11,  5, 13,  7, 15,  9, 17, -1, -1,
    -1,  4,  7,  2,  9,  1, 11,  3, 13,  5, 15,  7, 17,  9, 16, -1,
    -1,  7,  4,  9,  2, 11,  1, 13,  3, 15,  5, 17,  7, 16,  9, -1,
     7,  6,  9,  4, 11,  2, 13,  1, 15,  3, 17,  5, 16,  7, 14,  9,
     8,  9,  6, 11,  4, 13,  2, 15,  1, 17,  3, 16,  5, 14,  7,  9,
     9,  8, 11,  6, 13,  4, 15,  2, 17,  1, 16,  3, 14,  5, 12,  7,
    10, 11,  8, 13,  6, 15,  4, 17,  2, 16,  1, 14,  3, 12,  5,  7,
    11, 10, 13,  8, 15,  6, 17,  4, 16,  2, 14,  1, 12,  3, 10,  5,
    12, 13, 10, 15,  8, 17,  6, 16,  4, 14,  2, 12,  1, 10,  3,  5,
    -1, 12, 15, 10, 17,  8, 16,  6, 14,  4, 12,  2, 10,  1,  8, -1,
    -1, 15, 12, 17, 10, 16,  8, 14,  6, 12,  4, 10,  2,  8,  1, -1,
    -1, -1, 17, 12, 16, 10, 14,  8, 12,  6, 10,  4,  8,  2, -1, -1,
    -1, -1, -1, 16, 12, 14, 10, 12,  8, 10,  6,  8,  4, -1, -1, -1,
    -1, -1, -1, -1, -1, 12, 12, 10, 10,  8,  8, -1, -1, -1, -1, -1
};

const int8_t cathode_map[256] = {
    -1, -1, -1, -1, -1,  5,  7,  7,  9,  9, 11, -1, -1, -1, -1, -1,
    -1, -1, -1,  5,  3,  7,  5,  9,  7, 11,  9, 13, 11, -1, -1, -1,
    -1, -1,  5,  1,  7,  3,  9,  5, 11,  7, 13,  9, 15, 11, -1, -1,
    -1,  5,  2,  7,  1,  9,  3, 11,  5, 13,  7, 15,  9, 17, 11, -1,
    -1,  4,  7,  2,  9,  1, 11,  3, 13,  5, 15,  7, 17,  9, 16, -1,
     6,  7,  4,  9,  2, 11,  1, 13,  3, 15,  5, 17,  7, 16,  9, 14,
     7,  6,  9,  4, 11,  2, 13,  1, 15,  3, 17,  5, 16,  7, 14, 12,
     8,  9,  6, 11,  4, 13,  2, 15,  1, 17,  3, 16,  5, 14,  7, 12,
     9,  8, 11,  6, 13,  4, 15,  2, 17,  1, 16,  3, 14,  5, 12, 10,
    10, 11,  8, 13,  6, 15,  4, 17,  2, 16,  1, 14,  3, 12,  5, 10,
    11, 10, 13,  8, 15,  6, 17,  4, 16,  2, 14,  1, 12,  3, 10,  8,
    -1, 13, 10, 15,  8, 17,  6, 16,  4, 14,  2, 12,  1, 10,  3, -1,
    -1, 12, 15, 10, 17,  8, 16,  6, 14,  4, 12,  2, 10,  1,  8, -1,
    -1, -1, 12, 17, 10, 16,  8, 14,  6, 12,  4, 10,  2,  8, -1, -1,
    -1, -1, -1, 12, 16, 10, 14,  8, 12,  6, 10,  4,  8, -1, -1, -1,
    -1, -1, -1, -1, -1, 14, 10, 12,  8, 10,  6, -1, -1, -1, -1, -1
};

// Pin Mapping
struct PinMapping { GPIO_TypeDef* port; uint32_t pin_pos; };
static PinMapping pin_map[18];

static void InitPinMap() {
    pin_map[1]  = {GPIOA, 9};  pin_map[2]  = {GPIOA, 8};
    pin_map[3]  = {GPIOB, 15}; pin_map[4]  = {GPIOB, 14};
    pin_map[5]  = {GPIOB, 13}; pin_map[6]  = {GPIOB, 12};
    pin_map[7]  = {GPIOC, 6};  pin_map[8]  = {GPIOA, 5};
    pin_map[9]  = {GPIOA, 2};  pin_map[10] = {GPIOA, 0};
    pin_map[11] = {GPIOC, 3};  pin_map[12] = {GPIOC, 2};
    pin_map[13] = {GPIOC, 1};  pin_map[14] = {GPIOC, 0};
    pin_map[15] = {GPIOC, 15}; pin_map[16] = {GPIOC, 14};
    pin_map[17] = {GPIOC, 13};
}

static const uint32_t PORTA_MASK = (3u<<(0*2))|(3u<<(2*2))|(3u<<(5*2))|(3u<<(8*2))|(3u<<(9*2));
static const uint32_t PORTB_MASK = (3u<<(12*2))|(3u<<(13*2))|(3u<<(14*2))|(3u<<(15*2));
static const uint32_t PORTC_MASK = (3u<<(0*2))|(3u<<(1*2))|(3u<<(2*2))|(3u<<(3*2))|
                                    (3u<<(6*2))|(3u<<(13*2))|(3u<<(14*2))|(3u<<(15*2));

static inline void SetAllHiZ() {
    GPIOA->MODER &= ~PORTA_MASK;
    GPIOB->MODER &= ~PORTB_MASK;
    GPIOC->MODER &= ~PORTC_MASK;
}

static void ConfigureAllPinsAsOutput() {
    GPIO_InitTypeDef g = {0};
    g.Mode  = GPIO_MODE_OUTPUT_PP;
    g.Pull  = GPIO_NOPULL;
    g.Speed = GPIO_SPEED_FREQ_VERY_HIGH;
    uint16_t pA[] = {GPIO_PIN_0, GPIO_PIN_2, GPIO_PIN_5, GPIO_PIN_8, GPIO_PIN_9};
    uint16_t pB[] = {GPIO_PIN_12, GPIO_PIN_13, GPIO_PIN_14, GPIO_PIN_15};
    uint16_t pC[] = {GPIO_PIN_0, GPIO_PIN_1, GPIO_PIN_2, GPIO_PIN_3,
                     GPIO_PIN_6, GPIO_PIN_13, GPIO_PIN_14, GPIO_PIN_15};
    for (auto pin : pA) { g.Pin = pin; HAL_GPIO_Init(GPIOA, &g); }
    for (auto pin : pB) { g.Pin = pin; HAL_GPIO_Init(GPIOB, &g); }
    for (auto pin : pC) { g.Pin = pin; HAL_GPIO_Init(GPIOC, &g); }
}

static inline void LightLED(uint8_t idx) {
    int8_t a = anode_map[idx];
    int8_t c = cathode_map[idx];
    if (a < 1 || c < 1) return;
    PinMapping& am = pin_map[a];
    PinMapping& cm = pin_map[c];
    SetAllHiZ();
    am.port->MODER |= (1u << (am.pin_pos * 2));
    cm.port->MODER |= (1u << (cm.pin_pos * 2));
    am.port->BSRR   = (1u << am.pin_pos);
    cm.port->BSRR   = (1u << (cm.pin_pos + 16));
}

static uint8_t fb[2][256];
static volatile uint8_t fb_display = 0; 
static volatile uint8_t fb_write   = 1;  

static inline void FB_Flip() {
    fb_display ^= 1;
    fb_write   ^= 1;
}

static inline void FB_ClearWrite() {
    memset(fb[fb_write], 0, 256);
}

static void FB_SetPixel(float sx, float sy) {
    int x = (int)roundf(sx);
    int y = (int)roundf(sy);
    if (x == 0) x = (sx >= 0.0f) ? 1 : -1;
    if (y == 0) y = (sy >= 0.0f) ? 1 : -1;
    if (x < -8 || x > 8 || y < -8 || y > 8) return;
    int col = (x < 0) ? (x + 8) : (x + 7);
    int row = (y > 0) ? (8 - y) : (-y + 7);
    int idx  = row * 16 + col;
    if (idx >= 0 && idx < 256) fb[fb_write][idx] = 1;
}

static volatile uint16_t mux_led = 0;

extern "C" void HAL_TIM_PeriodElapsedCallback(TIM_HandleTypeDef* htim) {
    if (htim->Instance != TIM2) return;

    SetAllHiZ();

    uint16_t start = mux_led;
    do {
        mux_led = (mux_led + 1) & 0xFF;
        if (fb[fb_display][mux_led]) {
            LightLED((uint8_t)mux_led);
            return;
        }
    } while (mux_led != start);
}

// Fluid Simulation
struct Particle { float x, y, vx, vy; };
static Particle particles[NUM_PARTICLES];

static void InitParticles() {
    for (int i = 0; i < NUM_PARTICLES; i++) {
        float angle = ((float)i / NUM_PARTICLES) * 2.0f * (float)M_PI;
        float r = SIM_RADIUS * 0.5f * sqrtf((float)(i + 1) / NUM_PARTICLES);
        particles[i].x  =  r * cosf(angle);
        particles[i].y  = -SIM_RADIUS * 0.4f + r * 0.4f * sinf(angle);
        particles[i].vx = 0.0f;
        particles[i].vy = 0.0f;
    }
}

static void SimStep(float gx, float gy) {
    for (int i = 0; i < NUM_PARTICLES; i++) {
        particles[i].vx += gx * DT;
        particles[i].vy += gy * DT;
        particles[i].x  += particles[i].vx * DT;
        particles[i].y  += particles[i].vy * DT;
    }

    // Wall behavior
    for (int i = 0; i < NUM_PARTICLES; i++) {
        float dx   = particles[i].x;
        float dy   = particles[i].y;
        float dist = sqrtf(dx*dx + dy*dy);
        if (dist > SIM_RADIUS && dist > 0.001f) {
            float nx    = dx / dist;
            float ny    = dy / dist;
            float depth = dist - SIM_RADIUS;
            particles[i].x -= nx * depth;
            particles[i].y -= ny * depth;
            float dot = particles[i].vx * nx + particles[i].vy * ny;
            if (dot > 0.0f) {
                particles[i].vx -= RESTITUTION * dot * nx;
                particles[i].vy -= RESTITUTION * dot * ny;
                particles[i].vx *= DAMPING;
                particles[i].vy *= DAMPING;
            }
        }
    }

    // Particle to particle behavior
    for (int i = 0; i < NUM_PARTICLES; i++) {
        for (int j = i + 1; j < NUM_PARTICLES; j++) {
            float dx   = particles[i].x - particles[j].x;
            float dy   = particles[i].y - particles[j].y;
            float d2   = dx*dx + dy*dy;
            float min2 = PARTICLE_REPULSE * PARTICLE_REPULSE;
            if (d2 < min2 && d2 > 0.0001f) {
                float d = sqrtf(d2);
                float s = (PARTICLE_REPULSE - d) / d * 0.5f;
                particles[i].x += dx * s; particles[i].y += dy * s;
                particles[j].x -= dx * s; particles[j].y -= dy * s;
            }
        }
    }
}

// Accelerometer Functions
static volatile uint8_t device_id_ad = 0;

static void ADXL363_Init() {
    HAL_GPIO_WritePin(GPIOA, GPIO_PIN_4, GPIO_PIN_SET);
    HAL_Delay(10);
    uint8_t tx[3] = {0x0B, 0x00, 0x00}, rx[3] = {0};
    HAL_GPIO_WritePin(GPIOA, GPIO_PIN_4, GPIO_PIN_RESET);
    HAL_SPI_TransmitReceive(&hspi1, tx, rx, 3, 100);
    HAL_GPIO_WritePin(GPIOA, GPIO_PIN_4, GPIO_PIN_SET);
    device_id_ad = rx[2];
    if (device_id_ad == 0xAD) {
        uint8_t pw[3] = {0x0A, 0x2D, 0x02};
        HAL_GPIO_WritePin(GPIOA, GPIO_PIN_4, GPIO_PIN_RESET);
        HAL_SPI_Transmit(&hspi1, pw, 3, 100);
        HAL_GPIO_WritePin(GPIOA, GPIO_PIN_4, GPIO_PIN_SET);
        HAL_Delay(10);
    }
}

static void ADXL363_ReadGravity(float* gx_out, float* gy_out) {
    if (device_id_ad != 0xAD) {
        *gx_out = 0.0f;
        *gy_out = -GRAVITY_STRENGTH;
        return;
    }
    uint8_t tx[8] = {0x0B, 0x0E, 0,0,0,0,0,0}, rx[8] = {0};
    HAL_GPIO_WritePin(GPIOA, GPIO_PIN_4, GPIO_PIN_RESET);
    HAL_SPI_TransmitReceive(&hspi1, tx, rx, 8, 100);
    HAL_GPIO_WritePin(GPIOA, GPIO_PIN_4, GPIO_PIN_SET);
    int16_t raw_x = (int16_t)((rx[3] << 8) | rx[2]);
    int16_t raw_y = (int16_t)((rx[5] << 8) | rx[4]);
    float ax = raw_x / 1000.0f;
    float ay = raw_y / 1000.0f;
    float mag = sqrtf(ax*ax + ay*ay);
    if (mag > 1.0f) { ax /= mag; ay /= mag; }
    *gx_out =  ax * GRAVITY_STRENGTH;
    *gy_out = -ay * GRAVITY_STRENGTH;
}

// Sleep Wake Function
static bool CheckActivity(float gx, float gy, float prev_gx, float prev_gy) {
    float dx = gx - prev_gx;
    float dy = gy - prev_gy;
    return (dx*dx + dy*dy) > (ACTIVITY_THRESHOLD * ACTIVITY_THRESHOLD);
}

static void GoToSleep() {
    is_sleeping = true;
    HAL_TIM_Base_Stop_IT(&htim2);
    SetAllHiZ();
}

static void WakeUp(float gx, float gy) {
    is_sleeping = false;
    FB_ClearWrite();
    for (int i = 0; i < NUM_PARTICLES; i++) FB_SetPixel(particles[i].x, particles[i].y);
    FB_Flip();
    mux_led = 0;
    HAL_TIM_Base_Start_IT(&htim2);
}

// Main
int main(void) {
    HAL_Init();
    SystemClock_Config();
    MX_GPIO_Init();
    MX_SPI1_Init();
    MX_ICACHE_Init();
    MX_TIM2_Init();

#ifdef PWR_UCPDR_UCPD_DBDIS
    __HAL_RCC_PWR_CLK_ENABLE();
    PWR->UCPDR |= PWR_UCPDR_UCPD_DBDIS;
#endif

    InitPinMap();
    ConfigureAllPinsAsOutput();
    ADXL363_Init();
    InitParticles();

    FB_ClearWrite();
    for (int i = 0; i < NUM_PARTICLES; i++) FB_SetPixel(particles[i].x, particles[i].y);
    FB_Flip();

    HAL_TIM_Base_Start_IT(&htim2);

    float gx = 0.0f, gy = -GRAVITY_STRENGTH;
    int accel_counter   = 0;
    int physics_counter = 0;
    int inactivity_count = 0;

    while (1) {
        static uint32_t last_tick = 0;
        while ((HAL_GetTick() - last_tick) < 16);
        last_tick = HAL_GetTick();

        if (!is_sleeping) {
            physics_counter++;
            if (physics_counter >= PHYSICS_STEPS_PER_PASS) {
                physics_counter = 0;
                SimStep(gx, gy);
                FB_ClearWrite();
                for (int i = 0; i < NUM_PARTICLES; i++) FB_SetPixel(particles[i].x, particles[i].y);
                FB_Flip();
            }
        }

        accel_counter++;
        if (accel_counter >= ACCEL_READ_INTERVAL) {
            accel_counter = 0;

            float prev_gx = gx, prev_gy = gy;
            ADXL363_ReadGravity(&gx, &gy);

            if (is_sleeping) {
                if (CheckActivity(gx, gy, prev_gx, prev_gy)) {
                    inactivity_count = 0;
                    WakeUp(gx, gy);
                }
            } else {
                if (CheckActivity(gx, gy, prev_gx, prev_gy)) {
                    inactivity_count = 0;
                } else {
                    inactivity_count++;
                    if (inactivity_count >= INACTIVITY_COUNT_MAX) {
                        inactivity_count = 0;
                        GoToSleep();
                    }
                }
            }
        }
    }
}

// System
extern "C" void SystemClock_Config(void) {
    RCC_OscInitTypeDef RCC_OscInitStruct = {0};
    RCC_ClkInitTypeDef RCC_ClkInitStruct = {0};

    __HAL_PWR_VOLTAGESCALING_CONFIG(PWR_REGULATOR_VOLTAGE_SCALE1);
    while (!__HAL_PWR_GET_FLAG(PWR_FLAG_VOSRDY)) {}

    RCC_OscInitStruct.OscillatorType      = RCC_OSCILLATORTYPE_MSI;
    RCC_OscInitStruct.MSIState            = RCC_MSI_ON;
    RCC_OscInitStruct.MSICalibrationValue = RCC_MSICALIBRATION_DEFAULT;
    RCC_OscInitStruct.MSIClockRange       = RCC_MSIRANGE_4;
    RCC_OscInitStruct.PLL.PLLState        = RCC_PLL_ON;
    RCC_OscInitStruct.PLL.PLLSource       = RCC_PLLSOURCE_MSI;
    RCC_OscInitStruct.PLL.PLLMBOOST       = RCC_PLLMBOOST_DIV1;
    RCC_OscInitStruct.PLL.PLLM            = 1;
    RCC_OscInitStruct.PLL.PLLN            = 80;
    RCC_OscInitStruct.PLL.PLLP            = 2;
    RCC_OscInitStruct.PLL.PLLQ            = 2;
    RCC_OscInitStruct.PLL.PLLR            = 2;
    RCC_OscInitStruct.PLL.PLLRGE          = RCC_PLLVCIRANGE_0;
    RCC_OscInitStruct.PLL.PLLFRACN        = 0;
    if (HAL_RCC_OscConfig(&RCC_OscInitStruct) != HAL_OK) Error_Handler();

    RCC_ClkInitStruct.ClockType      = RCC_CLOCKTYPE_HCLK | RCC_CLOCKTYPE_SYSCLK |
                                       RCC_CLOCKTYPE_PCLK1 | RCC_CLOCKTYPE_PCLK2 |
                                       RCC_CLOCKTYPE_PCLK3;
    RCC_ClkInitStruct.SYSCLKSource   = RCC_SYSCLKSOURCE_PLLCLK;
    RCC_ClkInitStruct.AHBCLKDivider  = RCC_SYSCLK_DIV1;
    RCC_ClkInitStruct.APB1CLKDivider = RCC_HCLK_DIV1;
    RCC_ClkInitStruct.APB2CLKDivider = RCC_HCLK_DIV1;
    RCC_ClkInitStruct.APB3CLKDivider = RCC_HCLK_DIV1;
    if (HAL_RCC_ClockConfig(&RCC_ClkInitStruct, FLASH_LATENCY_4) != HAL_OK) Error_Handler();
}

extern "C" void Error_Handler(void) {
    __disable_irq();
    while (1) {}
}

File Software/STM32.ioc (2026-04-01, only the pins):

Mcu.UserName=STM32U575RGTx
PA0.Signal=GPIO_Output
PA1.Signal=SPI1_SCK
PA11.Signal=USB_OTG_FS_DM
PA12.Signal=USB_OTG_FS_DP
PA2.Signal=GPIO_Output
PA4.Signal=GPIO_Output
PA5.Signal=GPIO_Output
PA6.Signal=SPI1_MISO
PA7.Signal=SPI1_MOSI
PA8.Signal=GPIO_Output
PA9.Signal=GPIO_Output
PB0.Signal=GPXTI0
PB12.Signal=GPIO_Output
PB13.Signal=GPIO_Output
PB14.Signal=GPIO_Output
PB15.Signal=GPIO_Output
PC0.Signal=GPIO_Output
PC1.Signal=GPIO_Output
PC13.Signal=GPIO_Output
PC2.Signal=GPIO_Output
PC3.Signal=GPIO_Output
PC5.Signal=GPIO_Input
PC6.Signal=GPIO_Output
